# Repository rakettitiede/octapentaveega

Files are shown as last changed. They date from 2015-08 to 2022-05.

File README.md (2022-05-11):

# OctaPentaVeega

Fun hobby project to generate 32 x 16 characters of text on VGA output (or alternatively 64x64 pixel graphics, or split-screen graphics/text) from Attiny85 with 6x10 pixel font.

Data is read from UART at 9600bps. [Subset of ANSI escapes is supported](https://github.com/Jartza/octapentaveega/blob/master/vga_uart_protocol.txt).

Wiring 3 Attinys together gets you 8 color output :)

Links:
* <a href="https://www.youtube.com/watch?v=G1QWNDck0yU" target="_blank">Video: Ansi tester 8-color (ansitester.py)</a>
* <a href="https://www.youtube.com/watch?v=Vw5xGuLFy8Q" target="_blank">Video: Ansi tester Black & White (ansitester.py)</a>
* <a href="https://www.youtube.com/watch?v=YL0RwEtTN70" target="_blank">Video: Graphics mode (tricoder) & left scroll</a>
* <a href="https://www.youtube.com/watch?v=1iC2AHI5caI" target="_blank">Video: Full screen scroll (B/W)</a>
* <a href="https://www.youtube.com/watch?v=936m7FMS__c" target="_blank">Video: Full screen scroll (8-color)</a>
* <a href="https://drive.google.com/file/d/0B2dTzW9TMeBxN29YOVFsZFJ2Sm8/view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" target="_blank">Video: Multiple individual rows scroll (B/W)</a>
* <a href="https://drive.google.com/file/d/0B2dTzW9TMeBxQ1luNFhwcXl3QjA/view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" target="_blank">Picture: 6x10 pixel font</a>
* <a href="https://drive.google.com/file/d/0B2dTzW9TMeBxRzJOQVZMNFE0STg/view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" target="_blank">Picture: Generic (B/W)</a>

Board photos:
* <a href="https://drive.google.com/file/d/0B2dTzW9TMeBxaFFxam1uVW05NlE/view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" target="_blank">B/W board</a>
* <a href="https://drive.google.com/file/d/0B2dTzW9TMeBxRXVzSUNCT1h2NHM/view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" target="_blank">8-color board</a>
* <a href="https://drive.google.com/file/d/0B2dTzW9TMeBxX2VmQmw3aXhWUDA/view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" target="_blank">8-color board back</a>
* <a href="https://drive.google.com/file/d/0B2dTzW9TMeBxUDQ4QUduWDV2TFE/view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" target="_blank">Arduino shield, 8-color with level shifter (3.3 / 5v compatible)</a>

<p>
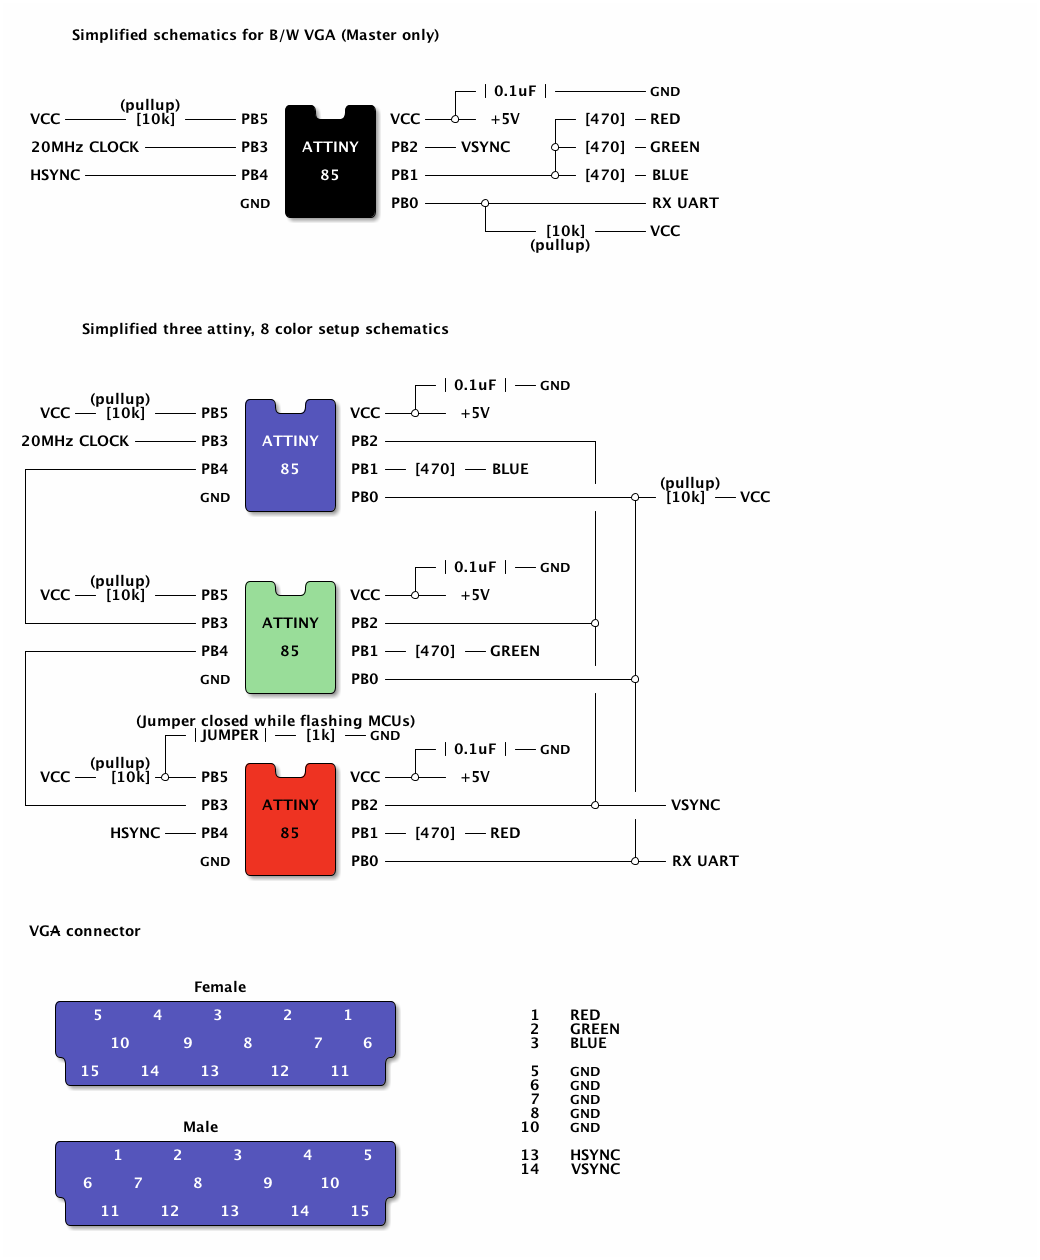
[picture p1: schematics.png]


//Jartza

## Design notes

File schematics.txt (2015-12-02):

Simplified schematics for B/W VGA (Master only):

                                           +--|0.1uF|----------GND
         (pullup)         /--\  /--\       |                                 
 VCC-------[10k]------PB5 |  \--/  | VCC---*-- +5V   +--[470]--RED
                          |cBLK    |                 |
 20MHz CLOCK----------PB3 | ATTINY | PB2----VSYNC    *--[470]--GREEN
                          |        |                 |
 HSYNC----------------PB4 |   85   | PB1-------------*--[470]--BLUE
                          |        |
                      GND |        | PB0------*----------------RX UART
                          \--------/          |
                                              +-----[10k]------VCC
                                                  (pullup)

Simplified three attiny, 8 color setup schematics:

                                       +--|0.1uF|---GND       
      (pullup)        /--\  /--\       |                      
  VCC---[10k]-----PB5 |  \--/  | VCC---*--- +5V                
                      |cBLU    |             
20MHz CLOCK-------PB3 | ATTINY | PB2---------------------+ 
                      |        |                         |     
+-----------------PB4 |   85   | PB1---[470]---BLUE      |   
|                     |        |                         |     (pullup)
|                 GND |        | PB0-------------------------*--[10k]---VCC
|                     \--------/                         |   |
|                                                        |   |
|                                                        |   |
|                                                        |   |
|                                      +--|0.1uF|---GND  |   |
|     (pullup)        /--\  /--\       |                 |   |
| VCC---[10k]-----PB5 |  \--/  | VCC---*--- +5V          |   |
|                     |cGRE    |                         |   |
+-----------------PB3 | ATTINY | PB2---------------------*   |
                      |        |                         |   |
+-----------------PB4 |   85   | PB1---[470]---GREEN     |   |
|                     |        |                         |   |
|                 GND |        | PB0-------------------------*
|                     \--------/                         |   |
|                                                        |   |
|       (Jumper closed while flashing MCUs)              |   |
|             +--|JUMPER|---[1k]---GND                   |   |
|             |                        +--|0.1uF|---GND  |   |
|    (pullup) |       /--\  /--\       |                 |   |
| VCC---[10k]-*---PB5 |  \--/  | VCC---*--- +5V          |   |
|                     |cRED    |                         |   |
+---------------- PB3 | ATTINY | PB2---------------------*-------VSYNC
                      |        |                             |
         HSYNC----PB4 |   85   | PB1---[470]---RED           |
                      |        |                             |
                  GND |        | PB0-------------------------*---RX UART
                      \--------/ 

VGA-connector:

                 Female                                                                     
   /---------------------------------\                                                    
   |   5     4     3      2     1    |             1 = RED
   |cBLU                             |             2 = GREEN
   |     10     9     8      7    6  |             3 = BLUE                                    
   \\                               //                                            
    | 15    14    13     12    11   |              5 = GND                           
    \-------------------------------/              6 = GND                                          
                                                   7 = GND                       
                                                   8 = GND                          
                Male                              10 = GND
   /---------------------------------\                                                    
   |     1     2     3      4     5  |            13 = HSYNC
   |cBLU                             |            14 = VSYNC
   |  6    7     8      9     10     |                                                         
   \\                               //                                            
    |   11    12    13     14    15 |                                              
    \-------------------------------/

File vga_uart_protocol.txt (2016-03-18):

Attiny85 VGA UART transfer:
===========================

Ascii-codes 32 .. 159 (decimal) are printed on screen as-is.

CR and LF are both treated as same; cursor is placed into
the beginning of next line. If cursor is already on last line, 
screen is scrolled up.

Limited subset of ANSI escapes is supported, and also few non-standard
escape codes.

ANSI sequence begins when "Escape" 0x1B (ascii 27 / ESC) character
followed by [ character is encountered.

List of supported ANSI escapes:
-----------------------------------------------------------------------------
Move cursor location		<ESC>[#row#;#column#H	#row# = 0 .. 13
				<ESC>[#row#;#column#f	#colunn# = 0 .. 31

Leaving both values undefined moves to (0,0):
<ESC>[H is equal to <ESC>[0;0H

Moving cursor outside the specified area has undefined effect.
-----------------------------------------------------------------------------
Clear screen and move cursor	<ESC>[2J
to upper left corner (0,0)
-----------------------------------------------------------------------------
Set colors (or reset to		<ESC>[#color#;#color#m
default color). Selected
color will stay active until
reset or new color selected.

#color# = color number		Foreground	Background
	black			   30		   40
	red			   31		   41
	green			   32		   42
	yellow			   33		   43
	blue			   34		   44
	magenta			   35		   45
	cyan			   36		   46
	white			   37		   47
	reset to defaults	   0

Color command supports maximum two arguments. Suggested way is to use
value 0 only alone in a command: <ESC>[0m resets colors to default.

Example: <ESC>[34;47m activates blue text with white background color.

Using other than supported color numbers has undefined effect.
-----------------------------------------------------------------------------
Disable wrap at the end		<ESC>[?7l	(lowercase L)
of line (cursor stays
in the last column).
-----------------------------------------------------------------------------
Enable wrap at the end		<ESC>[?7h
of line (cursor advances
to next line). Default
mode.
-----------------------------------------------------------------------------

Non-standard Escape codes
-----------------------------------------------------------------------------
Reset device			<ESC>c		Resets all variables and
						reboots device. Wait 1 second
						after this command before 
						sending new data.
-----------------------------------------------------------------------------
Scroll full screen left		<ESC>D		(Notice missing [ -char)
one column, emptying last
character of every row

Scroll commands are buffered if sent before the actual scroll has commenced.
-----------------------------------------------------------------------------
Scroll row left one 		<ESC>[#row#[	#row# = 0 .. 15
column, emptying last
character on row.

Example: <ESC>[9[ scrolls row 9 (10th row) left one column.
-----------------------------------------------------------------------------
Move cursor down		<ESC>[B		Moves cursor down.
-----------------------------------------------------------------------------
Move cursor forward		<ESC>[C		Moves cursor forward.
-----------------------------------------------------------------------------
Graphics/Text-mode split	<ESC>[#row#]	#row# = 0 .. 16
						Text-mode starts from #row#
						0 = full text
						16 = full graphics
						1..15 = split screen to
						        graphics / text
-----------------------------------------------------------------------------
Tricoder mode start		<ESC>G		In tricoder mode, each byte
						is sent 3 times: 
						Red, Green and Blue value
						separately. Useful in
						graphics mode as it allows
						you to draw any pixel
						with any of the 8 colors.
-----------------------------------------------------------------------------
Tricoder mode end		<ESC>T
-----------------------------------------------------------------------------
<ESC> followed by any other character than command prints the character to 
screen buffer as-is. 

Following ascii codes need to be escaped, if you want to print them to screen:
8, 10, 13, 27, 127

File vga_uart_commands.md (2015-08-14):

Attiny85 VGA ANSI escape codes:
===============================

Attiny85 VGA supports a limited subset of ANSI escapes.

ANSI sequence begins when "Escape" 0x1B (ascii 27 / ESC) character
followed by [ character is encountered.

Following ANSI escapes are supported:
-----------------------------------------------------------------------------
Move cursor location		<ESC>[#row#;#column#H	#row# = 0 .. 13
				<ESC>[#row#;#column#f	#colunn# = 0 .. 31

Leaving both values undefined moves to (0,0):
<ESC>[H is equal to <ESC>[0;0H

Moving cursor outside defined area has undefined effect.
-----------------------------------------------------------------------------
Clear screen and move cursor	<ESC>[2J
to upper left corner (0,0)
-----------------------------------------------------------------------------
Set colors (or reset to		<ESC>[#color#;#color#m
default color). Selected
color will stay active until
reset or new color selected.

#color# = color number		Foreground	Background
	black			   30		   40
	red			   31		   41
	green			   32		   42
	yellow			   33		   43
	blue			   34		   44
	magenta			   35		   45
	cyan			   36		   46
	white			   37		   47
	reset to defaults	   0

Color command supports maximum two arguments. Suggested way is to use
value 0 only alone in a command: <ESC>[0m resets colors to default.

Example: <ESC>[34;47m activates blue text with white background color.
-----------------------------------------------------------------------------

<ESC><ESC> sends ASCII character 27 to screen.

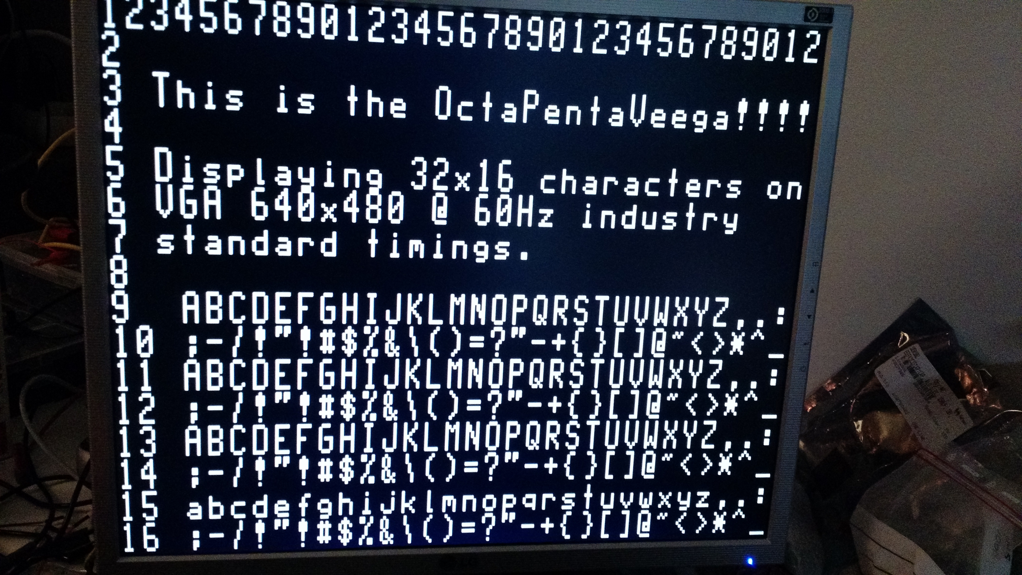
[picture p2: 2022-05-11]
pic/generic.jpg

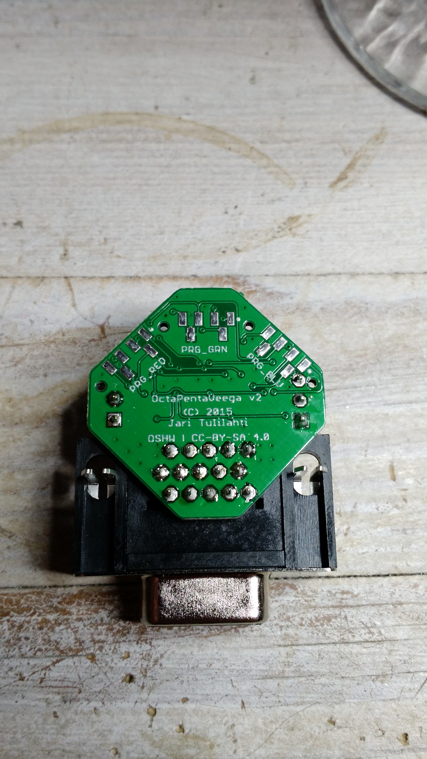
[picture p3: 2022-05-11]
pic/8colorboardback.jpg

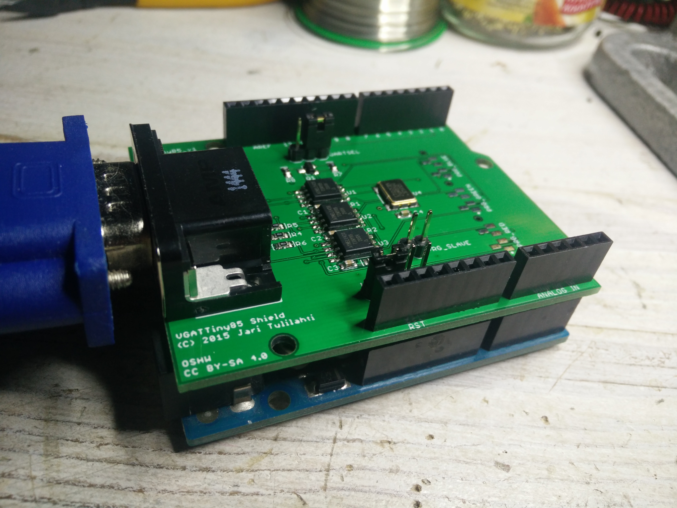
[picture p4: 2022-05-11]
pic/arduinoshield.jpg

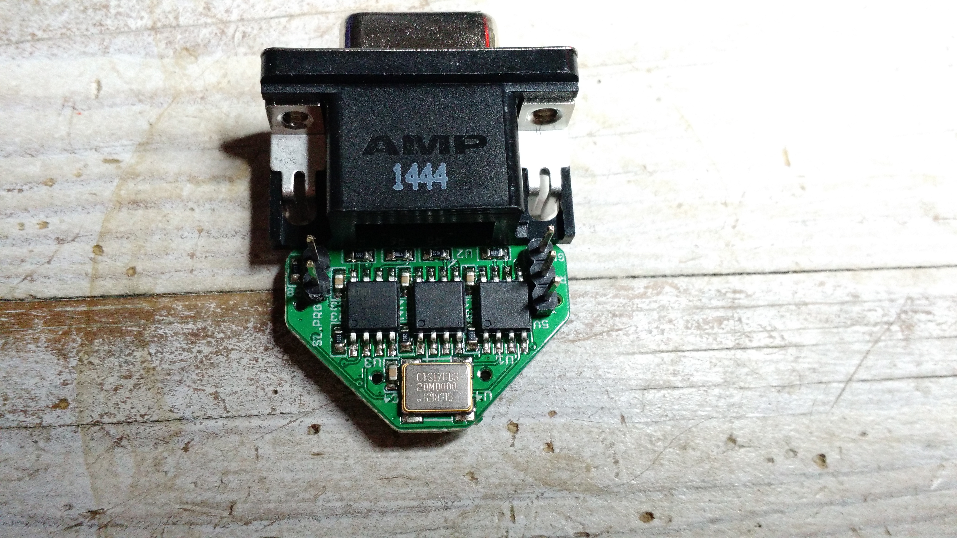
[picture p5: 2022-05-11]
pic/8colorboard.jpg

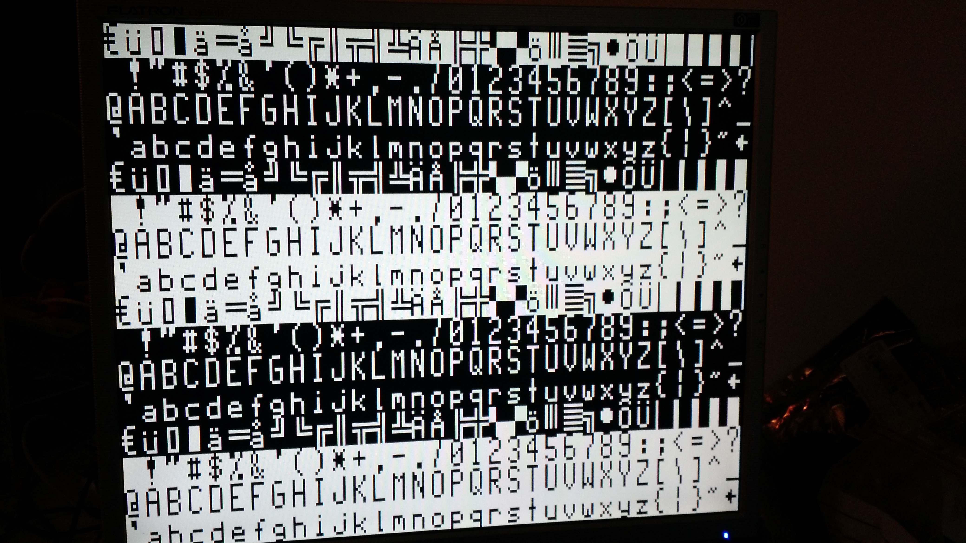
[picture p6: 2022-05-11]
pic/font.jpg

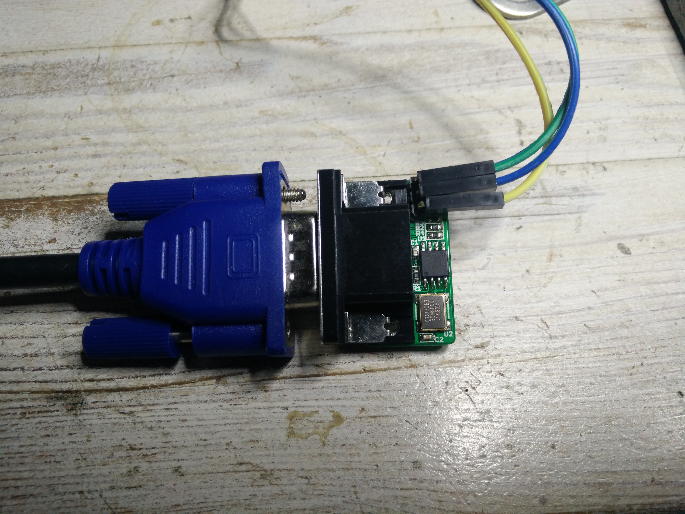
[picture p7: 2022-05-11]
pic/bwboard.jpg

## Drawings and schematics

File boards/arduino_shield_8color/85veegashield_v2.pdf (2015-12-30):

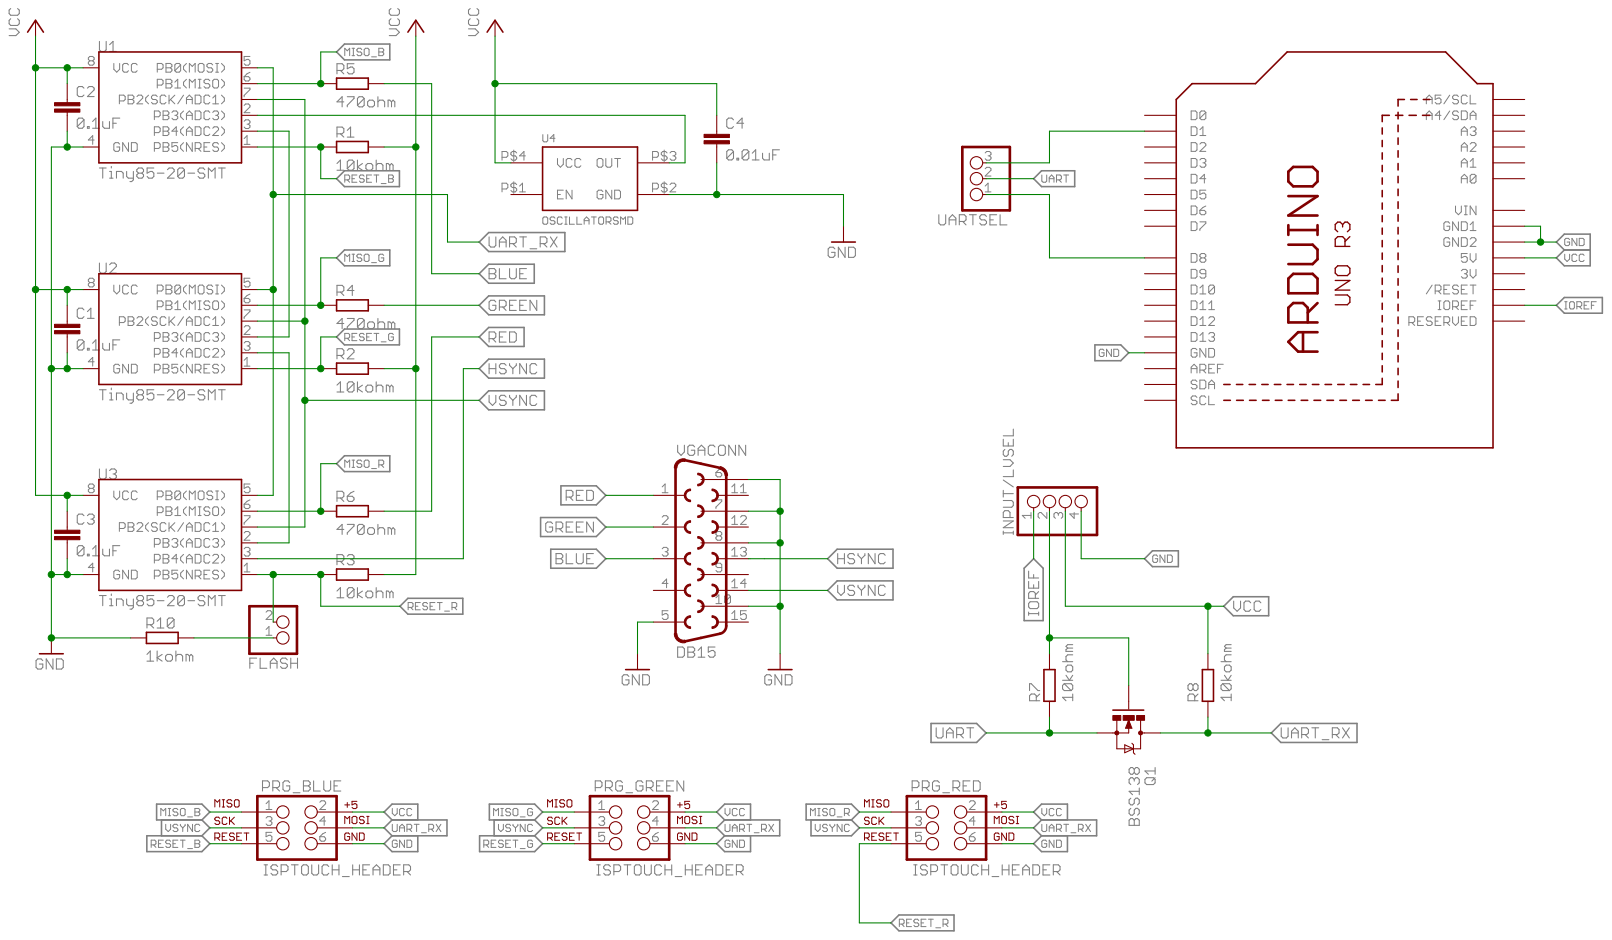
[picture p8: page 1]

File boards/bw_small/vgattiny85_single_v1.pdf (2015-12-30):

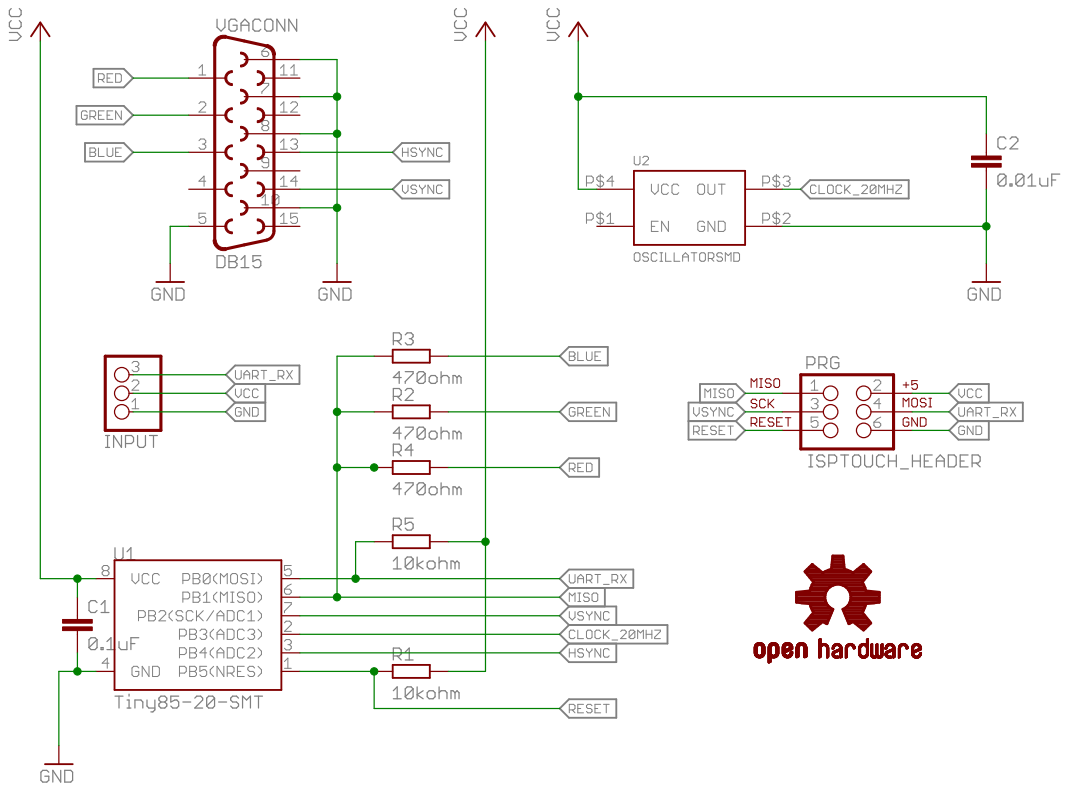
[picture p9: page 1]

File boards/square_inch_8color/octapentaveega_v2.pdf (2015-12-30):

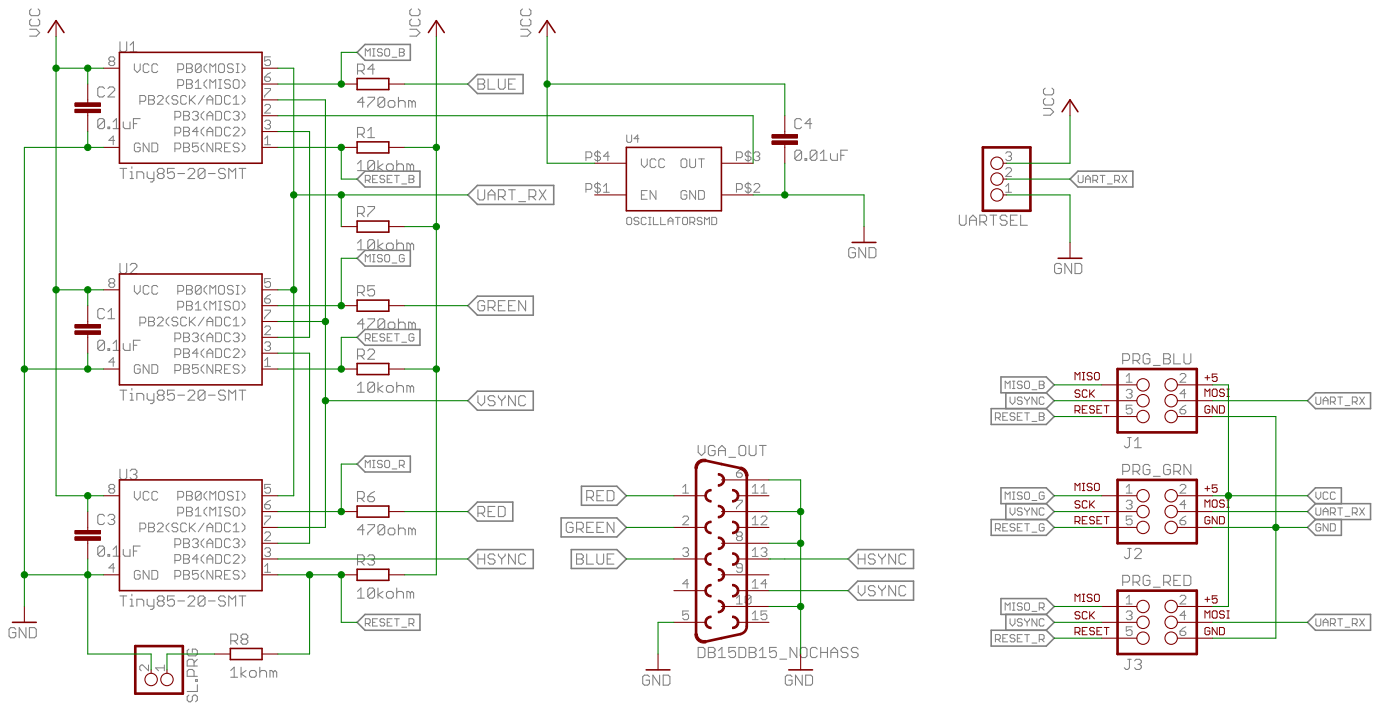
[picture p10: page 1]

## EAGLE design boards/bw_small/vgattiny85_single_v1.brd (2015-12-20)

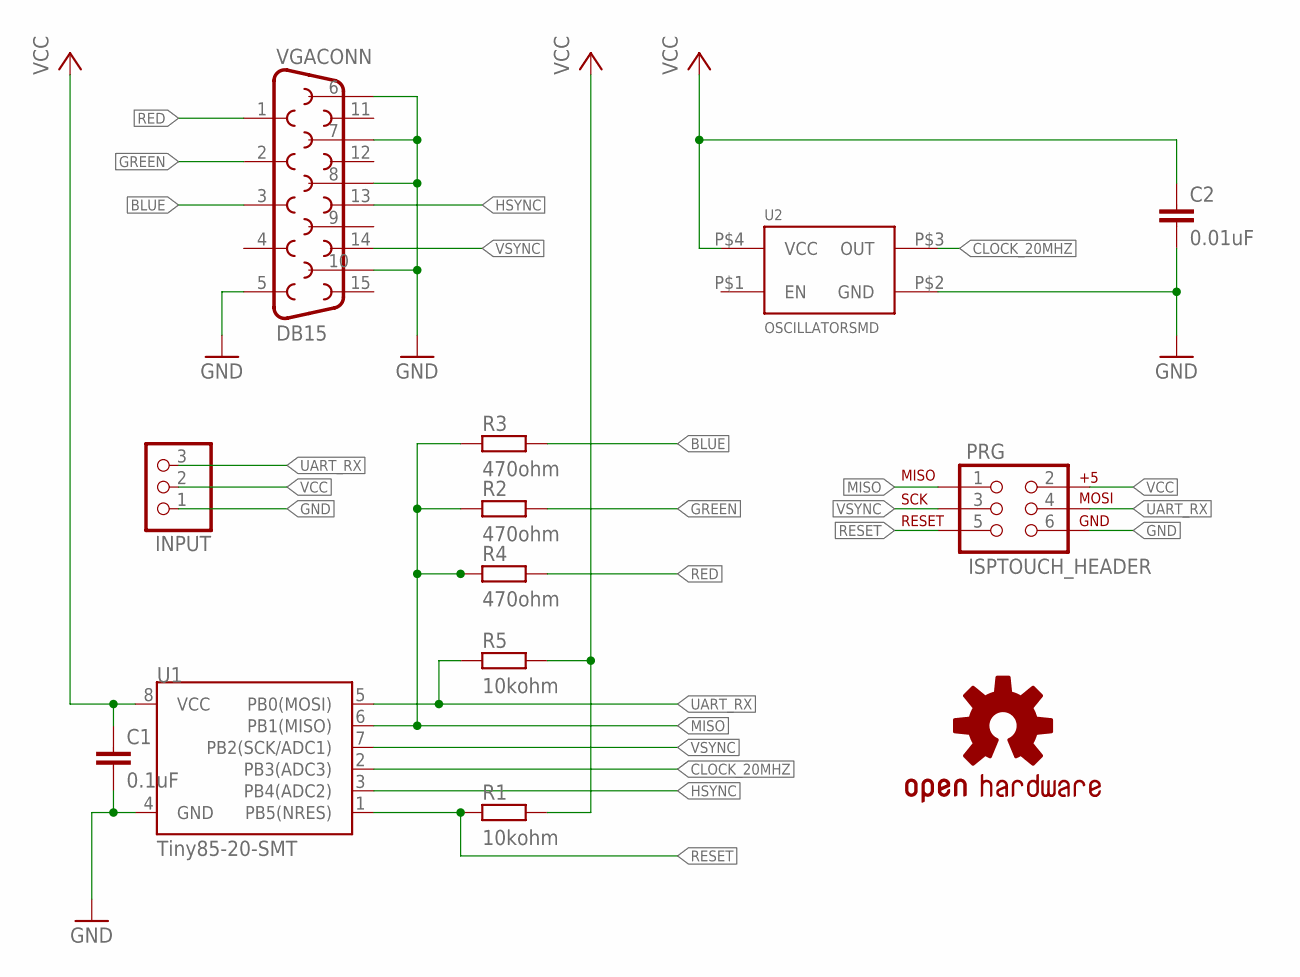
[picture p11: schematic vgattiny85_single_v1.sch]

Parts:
C1: 0.1uF; 0603-CAP
C2: 0.01uF; 0603-CAP
INPUT: PINHD-1X03_2.54-S; 1X03-S
LOGO1: OSHW-LOGOS; OSHW-LOGO-S
PRG: ISPTOUCH_HEADER; AVX_9188_6-WAY_MATING_GUIDE
R1, R5: 10kohm; R0603
R2, R3, R4: 470ohm; R0603
U1: Tiny85-20-SMT; SO08-EIAJ
U2: OSCILLATORSMD; CRYSTAL-SMD-7X5
VGACONN: DB15

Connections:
BLUE: R3.2, VGACONN.3
CLOCK_20MHZ: U1.2 (PB3(ADC3)), U2.P$3 (OUT)
GND: C1.2, C2.2, INPUT.1, PRG.6, U1.4 (GND), U2.P$2 (GND), VGACONN.5, VGACONN.6, VGACONN.7, VGACONN.8, VGACONN.10
GREEN: R2.2, VGACONN.2
HSYNC: U1.3 (PB4(ADC2)), VGACONN.13
MISO: PRG.1, R2.1, R3.1, R4.1, U1.6 (PB1(MISO))
RED: R4.2, VGACONN.1
RESET: PRG.5, R1.1, U1.1 (PB5(NRES))
UART_RX: INPUT.3, PRG.4, R5.1, U1.5 (PB0(MOSI))
VCC: C1.1, C2.1, INPUT.2, PRG.2, R1.2, R5.2, U1.8 (VCC), U2.P$4 (VCC)
VSYNC: PRG.3, U1.7 (PB2(SCK/ADC1)), VGACONN.14

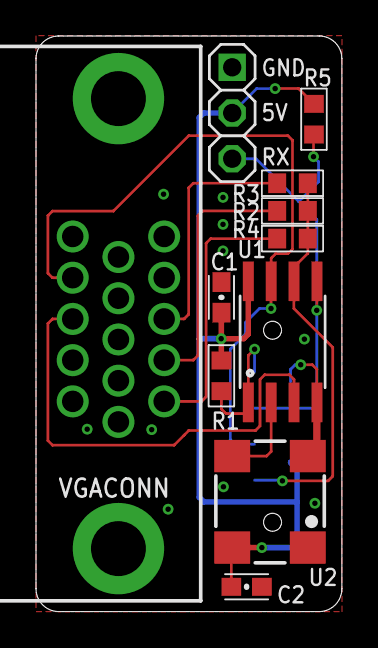
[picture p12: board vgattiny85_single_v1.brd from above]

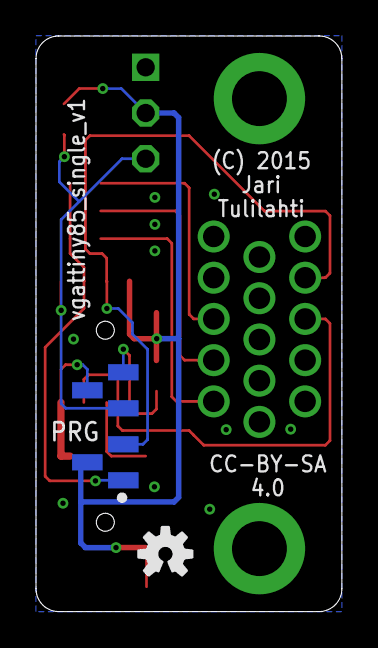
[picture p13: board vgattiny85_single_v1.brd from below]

Board: 2 copper layers, 17.0 x 32.0 mm, 13 parts (2 on the bottom side), 11 nets.

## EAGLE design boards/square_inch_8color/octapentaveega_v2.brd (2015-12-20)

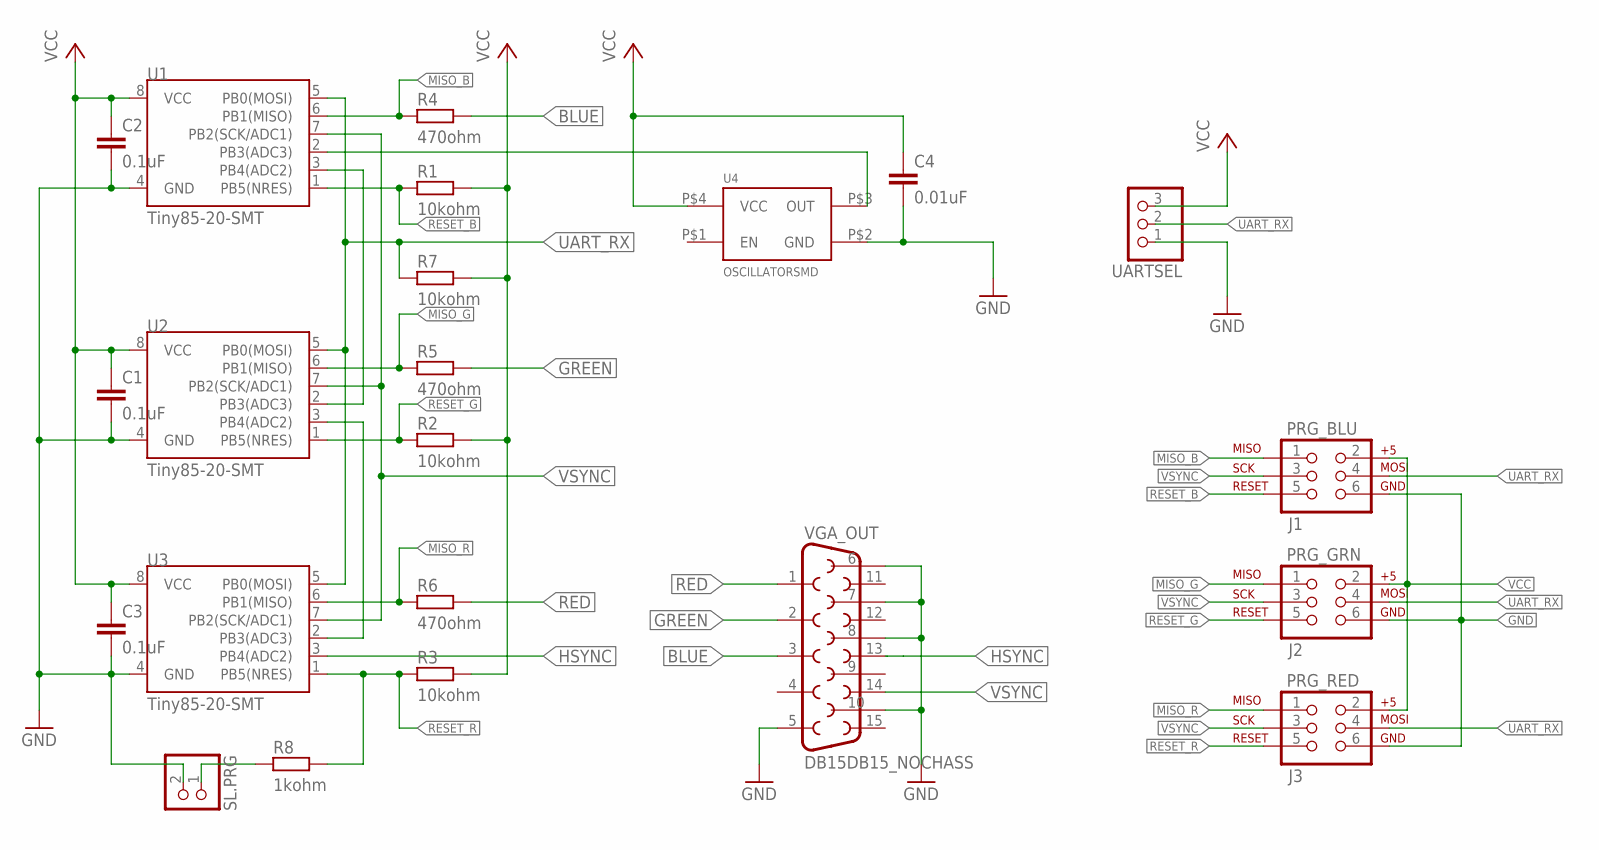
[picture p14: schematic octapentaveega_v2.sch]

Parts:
C1, C2, C3: 0.1uF; C0603
C4: 0.01uF; C0603
PRG_BLU: J1; AVX_9188_6-WAY_MATING_GUIDE
PRG_GRN: J2; AVX_9188_6-WAY_MATING_GUIDE
PRG_RED: J3; AVX_9188_6-WAY_MATING_GUIDE
R1, R2, R3, R7: 10kohm; R0603
R4, R5, R6: 470ohm; R0603
R8: 1kohm; R0603
SL.PRG: PINHD-1X02_2.54-S; 1X02-S
U1, U2, U3: Tiny85-20-SMT; SO08-EIAJ
U4: OSCILLATORSMD; CRYSTAL-SMD-7X5
UARTSEL: PINHD-1X03_2.54-S; 1X03-S
VGA_OUT: DB15DB15_NOCHASS; DB15_NOCHASS

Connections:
BLUE: R4.2, VGA_OUT.3
GND: C1.2, C2.2, C3.2, C4.2, PRG_BLU.6, PRG_GRN.6, PRG_RED.6, SL.PRG.2, U1.4 (GND), U2.4 (GND), U3.4 (GND), U4.P$2 (GND), UARTSEL.1, VGA_OUT.5, VGA_OUT.6, VGA_OUT.7, VGA_OUT.8, VGA_OUT.10
GREEN: R5.2, VGA_OUT.2
HSYNC: U3.3 (PB4(ADC2)), VGA_OUT.13
MISO_B: PRG_BLU.1, R4.1, U1.6 (PB1(MISO))
MISO_G: PRG_GRN.1, R5.1, U2.6 (PB1(MISO))
MISO_R: PRG_RED.1, R6.1, U3.6 (PB1(MISO))
unnamed: U1.2 (PB3(ADC3)), U4.P$3 (OUT)
unnamed: U1.3 (PB4(ADC2)), U2.2 (PB3(ADC3))
unnamed: U2.3 (PB4(ADC2)), U3.2 (PB3(ADC3))
unnamed: R8.1, SL.PRG.1
RED: R6.2, VGA_OUT.1
RESET_B: PRG_BLU.5, R1.1, U1.1 (PB5(NRES))
RESET_G: PRG_GRN.5, R2.1, U2.1 (PB5(NRES))
RESET_R: PRG_RED.5, R3.1, R8.2, U3.1 (PB5(NRES))
UART_RX: PRG_BLU.4, PRG_GRN.4, PRG_RED.4, R7.1, U1.5 (PB0(MOSI)), U2.5 (PB0(MOSI)), U3.5 (PB0(MOSI)), UARTSEL.2
VCC: C1.1, C2.1, C3.1, C4.1, PRG_BLU.2, PRG_GRN.2, PRG_RED.2, R1.2, R2.2, R3.2, R7.2, U1.8 (VCC), U2.8 (VCC), U3.8 (VCC), U4.P$4 (VCC), UARTSEL.3
VSYNC: PRG_BLU.3, PRG_GRN.3, PRG_RED.3, U1.7 (PB2(SCK/ADC1)), U2.7 (PB2(SCK/ADC1)), U3.7 (PB2(SCK/ADC1)), VGA_OUT.14

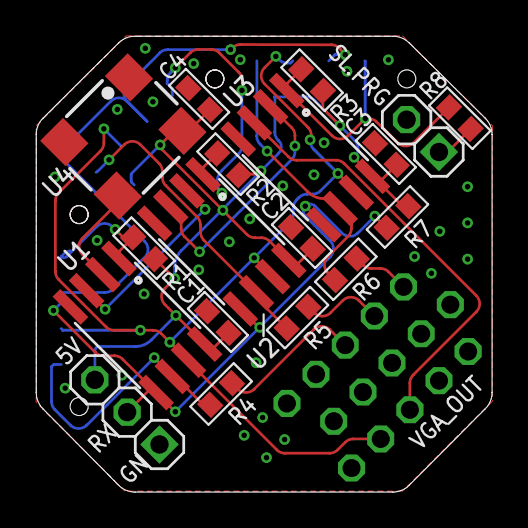
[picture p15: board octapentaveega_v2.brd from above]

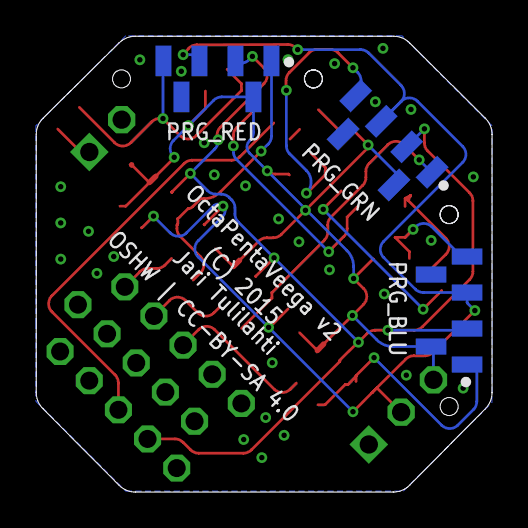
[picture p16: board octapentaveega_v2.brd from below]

Board: 2 copper layers, 25.3 x 25.3 mm, 22 parts (3 on the bottom side), 18 nets.

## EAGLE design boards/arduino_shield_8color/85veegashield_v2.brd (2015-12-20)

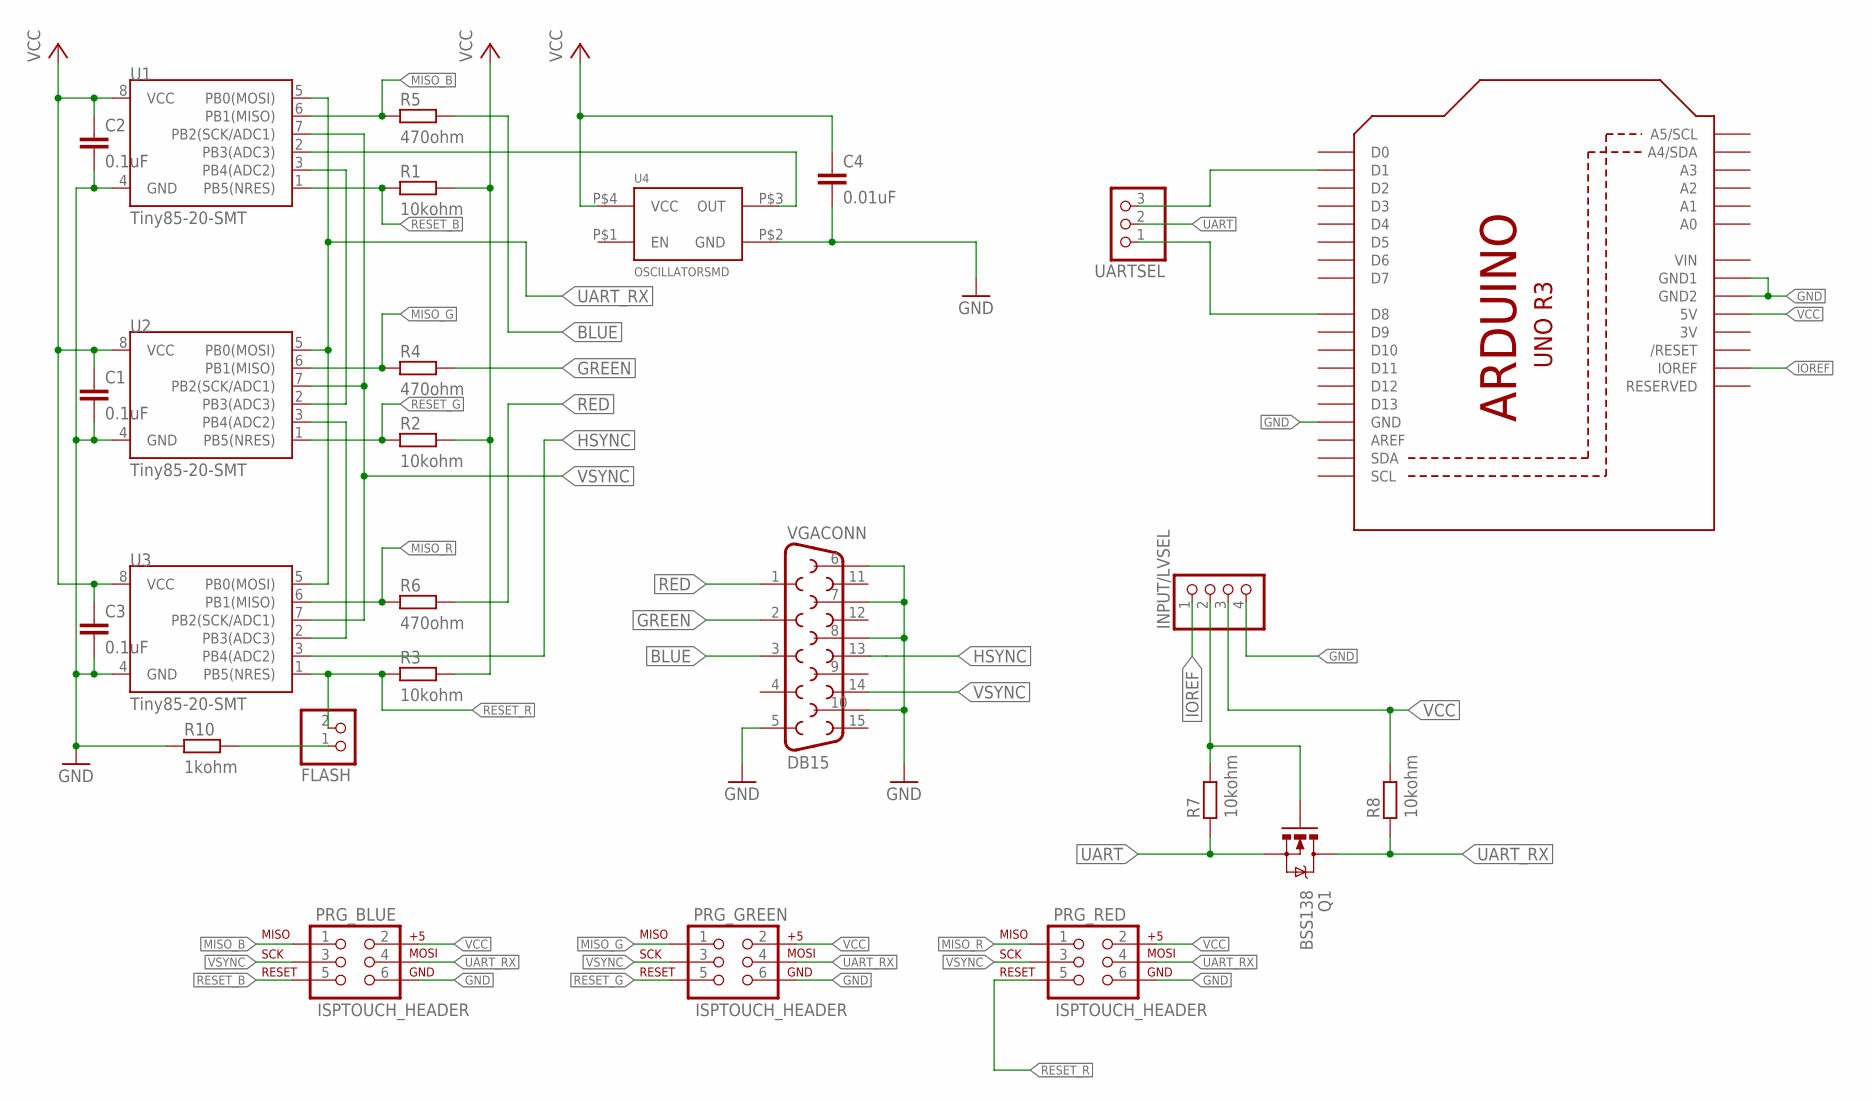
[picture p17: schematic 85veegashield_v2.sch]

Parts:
C1, C2, C3: 0.1uF; 0603-CAP
C4: 0.01uF; 0603-CAP
FLASH: PINHD-1X02_2.54-S; 1X02-S
INPUT/LVSEL: PINHD-1X04_2.54-S; 1X04-S
PRG_BLUE: ISPTOUCH_HEADER; AVX_9188_6-WAY_MATING_GUIDE
PRG_GREEN: ISPTOUCH_HEADER; AVX_9188_6-WAY_MATING_GUIDE
PRG_RED: ISPTOUCH_HEADER; AVX_9188_6-WAY_MATING_GUIDE
Q1: BSS138; SOT23
R1, R2, R3, R7, R8: 10kohm; R0603
R4, R5, R6: 470ohm; R0603
R10: 1kohm; R0603
U1, U2, U3: Tiny85-20-SMT; SO08-EIAJ
U4: OSCILLATORSMD; CRYSTAL-SMD-7X5
U$1: ARDUINOR3-DIMENSION; ARDUINOR3
UARTSEL: PINHD-1X03_2.54-S; 1X03-S
VGACONN: DB15

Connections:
3V: U$1.3V
BLUE: R5.2, VGACONN.3
FOO: INPUT/LVSEL.2, Q1.1 (G), R7.2
GND: C1.2, C2.2, C3.2, C4.2, INPUT/LVSEL.4, PRG_BLUE.6, PRG_GREEN.6, PRG_RED.6, R10.1, U1.4 (GND), U2.4 (GND), U3.4 (GND), U4.P$2 (GND), U$1.GND, U$1.GND1, U$1.GND2, VGACONN.5, VGACONN.6, VGACONN.7, VGACONN.8, VGACONN.10
GREEN: R4.2, VGACONN.2
HSYNC: U3.3 (PB4(ADC2)), VGACONN.13
IOREF: INPUT/LVSEL.1, U$1.IOREF
MISO_B: PRG_BLUE.1, R5.1, U1.6 (PB1(MISO))
MISO_G: PRG_GREEN.1, R4.1, U2.6 (PB1(MISO))
MISO_R: PRG_RED.1, R6.1, U3.6 (PB1(MISO))
unnamed: U1.2 (PB3(ADC3)), U4.P$3 (OUT)
unnamed: U1.3 (PB4(ADC2)), U2.2 (PB3(ADC3))
unnamed: U2.3 (PB4(ADC2)), U3.2 (PB3(ADC3))
unnamed: U$1.D1, UARTSEL.3
unnamed: FLASH.1, R10.2
unnamed: U$1.D8, UARTSEL.1
RED: R6.2, VGACONN.1
RESET_B: PRG_BLUE.5, R1.1, U1.1 (PB5(NRES))
RESET_G: PRG_GREEN.5, R2.1, U2.1 (PB5(NRES))
RESET_R: FLASH.2, PRG_RED.5, R3.1, U3.1 (PB5(NRES))
UART: Q1.2 (S), R7.1, UARTSEL.2
UART_RX: PRG_BLUE.4, PRG_GREEN.4, PRG_RED.4, Q1.3 (D), R8.1, U1.5 (PB0(MOSI)), U2.5 (PB0(MOSI)), U3.5 (PB0(MOSI))
VCC: C1.1, C2.1, C3.1, C4.1, INPUT/LVSEL.3, PRG_BLUE.2, PRG_GREEN.2, PRG_RED.2, R1.2, R2.2, R3.2, R8.2, U1.8 (VCC), U2.8 (VCC), U3.8 (VCC), U4.P$4 (VCC), U$1.5V
VIN: U$1.VIN
VSYNC: PRG_BLUE.3, PRG_GREEN.3, PRG_RED.3, U1.7 (PB2(SCK/ADC1)), U2.7 (PB2(SCK/ADC1)), U3.7 (PB2(SCK/ADC1)), VGACONN.14

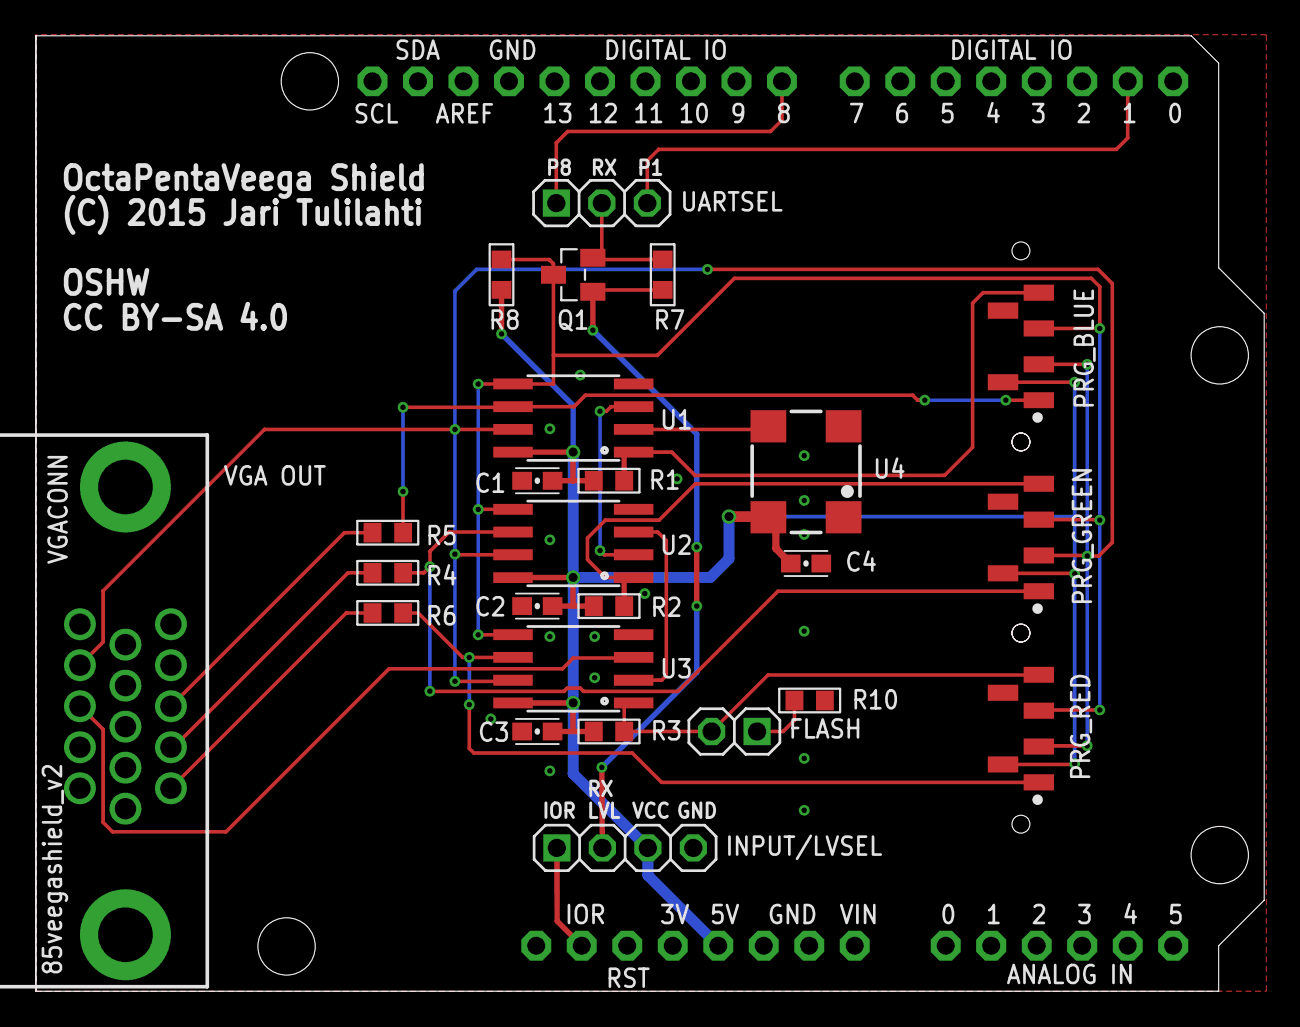
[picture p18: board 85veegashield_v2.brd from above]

Board: 2 copper layers, 68.6 x 53.3 mm, 26 parts (0 on the bottom side), 23 nets.

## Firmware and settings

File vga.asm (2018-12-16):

;;;;;;;;;;;;;;;;;;;;;;;;;;;;;;;;;;;;;;;;;;;;;;;;;;;;;;;;;;;;;;;;;;;;;;;;;;;;;;;;
;;                                                                            ;;
;;  32 x 16 character VGA output with UART for Attiny85.                      ;;
;;                                                                            ;;
;;  (C) Copyright 2015-2016 Jari Tulilahti                                    ;;
;;                                                                            ;;
;;  All right and deserved.                                                   ;;
;;                                                                            ;;
;;  Licensed under the Apache License, Version 2.0 (the "License");           ;;
;;  you may not use this file except in compliance with the License.          ;;
;;  You may obtain a copy of the License at                                   ;;
;;                                                                            ;;
;;      http://www.apache.org/licenses/LICENSE-2.0                            ;;
;;                                                                            ;;
;;  Unless required by applicable law or agreed to in writing, software       ;;
;;  distributed under the License is distributed on an "AS IS" BASIS,         ;;
;;  WITHOUT WARRANTIES OR CONDITIONS OF ANY KIND, either express or implied.  ;;
;;  See the License for the specific language governing permissions and       ;;
;;  limitations under the License.                                            ;;
;;                                                                            ;;
;;;;;;;;;;;;;;;;;;;;;;;;;;;;;;;;;;;;;;;;;;;;;;;;;;;;;;;;;;;;;;;;;;;;;;;;;;;;;;;;

.include "tn85def.inc"

; Registers have been named for easier access.
; in addition we use all of the X, Y and Z
; register pairs for pointers to different buffers
;
; X (r26:r27) is pointer to screen buffer, also used while
;             clearing the screen
; Y (r28:r29) is pointer to either predraw, or currently being
;             drawn buffer
; Z (r30:r31) pointer is used for fetching the data from flash
;             with lpm instruction
;

.def zero               = r0            ; Register for value 0
.def one                = r1            ; Register for value 1
.def seq_cnt            = r2            ; Counter for several sequences
.def row_cnt            = r3            ; Vertical pixel counter
.def char_row           = r4            ; Predraw-buffer x-offset
.def uart_seq           = r5            ; UART sequence
.def uart_next          = r6            ; Next UART sequence
.def clear_cnt          = r7            ; Screen clear counter
.def uart_byte          = r8            ; UART receiving counter & data
.def color_fg           = r9            ; Foreground color
.def color_bg           = r10           ; Background (4..7) color
.def ansi_val1          = r11           ; Storage for ANSI cmd value
.def ansi_val2          = r12           ; Storage for ANSI cmd value
.def vline_lo           = r13           ; Vertical line low byte
.def vline_hi           = r14           ; Vertical line high byte
.def scroll_row         = r15           ; Row number for horizontal scroll
.def temp               = r16           ; Temporary register
.def temp2              = r17           ; Temporary register 2
.def font_hi            = r18           ; Font Flash addr high byte
.def scroll_lo          = r19           ; Screen scroll offset low
.def scroll_hi          = r20           ; Screen scroll offset high
.def ansi_state         = r21           ; ANSI command states described below
.def uart_buf           = r22           ; UART buffer
.def state              = r23           ; Bitmask for states described below
.def cursor_lo          = r24           ; Cursor offset low
.def cursor_hi          = r25           ; Cursor offset high
                                        ; r26 .. r31 described above

; state: (bits)
;
.equ st_clear           = 0             ; Screen clear mode active bit
.equ st_wrap            = 1             ; Wrap mode active bit
.equ st_uart            = 2             ; UART data in buffer
.equ st_scroll          = 3             ; Scroll-clear in action
.equ st_left            = 4             ; Scroll row left
.equ st_full_left       = 5             ; Scroll full screen
.equ st_tricoder        = 6             ; "Tricoder"-mode
.equ st_clear_val       = (1 << 0)      ; Value to set/clear clear mode
.equ st_wrap_val        = (1 << 1)      ; Value to set/clear wrap mode
.equ st_uart_val        = (1 << 2)      ; Value to set/clear UART buffer state
.equ st_scroll_val      = (1 << 3)      ; Value to set/clear scroll-clear state
.equ st_left_val        = (1 << 4)      ; Value to set/clear row-scroll
.equ st_full_left_val   = (1 << 5)      ; Value to set/clear full-screen-scroll
.equ st_tricoder_val    = (1 << 6)      ; Value to set/clear tricoder

; ansi_state: (value)
;
; 0 : None
; 1 : ESC received
; 2 : Opening bracket "[" received
; 3 : Two values received


; Constants
;
.equ UART_WAIT          = 138           ; HSYNC timer value where we start to
                                        ; look for UART samples (or handle
                                        ; data received)
.equ HSYNC_WAIT         = 2             ; HSYNC value to start precalculating
                                        ; the pixels and drawing to screen
.equ JITTERVAL          = 248           ; Must be in sync with HSYNC_WAIT value.
                                        ; We want Timer0 counter to be 0-4 in
                                        ; jitterfix label. AVR Studio simulator
                                        ; was used to sync this value.
.equ VSYNC_LOW          = 490 - 256     ; Turn VSYNC low on this vertical line
.equ VSYNC_HIGH         = VSYNC_LOW + 2 ; Turn VSYNC high on this vertical line
.equ VISIBLE            = 480 - 256     ; Visible vline count
.equ UART_XOR           = 124           ; UART sequence magic XORing value
.equ UART_INIT          = 100           ; UART sequence initial value after start
.equ UART_FIRST         = 24            ; UART first sequence
.equ ALT_XOR            = 32            ; Buffer flipping value
.equ DEFAULT_COLOR_FG   = 7             ; White foreground
.equ DEFAULT_COLOR_BG   = 0             ; Black background

; Pins used for different signals
;
.equ UART_PIN           = PB0
.equ RGB_PIN            = PB1
.equ VSYNC_PIN          = PB2
.equ HSYNC_PIN          = PB4

; General purpose IO registers used as storage
;
.equ LEFT_CNT           = GPIOR0
.equ SPLIT_ROW          = GPIOR1
.equ TRICODE_CNT        = GPIOR2


; All of the 512 byte SRAM is used for screen buffer.
;
.dseg
.org 0x60

screenbuf:
        .byte 512
screen_end:

; Start the code section. 
; Only two vectors used. RESET for all versions
; and INT0 for slaves (synchronization)
.cseg
.org 0x00

vectors:
        rjmp main
.ifdef VGA_SLAVE
        rjmp slave_sync
.endif
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

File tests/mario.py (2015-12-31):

import serial
import time
import random
import sys

# Give port name of your UART as first argument. No error checking
# here, sorry.
#
ser = serial.Serial(sys.argv[1], 9600,  timeout = 1)

serwrite = lambda x: ser.write(bytearray(map(ord, x)))
move_to = lambda x, y: serwrite("\x1B[{0};{1}H".format(y, x))

#serwrite("xxxxx\x08") # dismiss if we're left in ANSI mode...
serwrite("\x1B[16]") # Graphics mode
serwrite("\x1B[m") # Reset colors
serwrite("\x1B[?7l") # disable wrap
serwrite("\x1BG") # Tricoder mode

mario=[
#red
[
"                                                                                                                                                                                                                                                                                                                                                                                                                                                                                                                                                                                                                                                                                                                                                                                                                                                                                                                                                                                                       ",
"                                                                                                                                                                                                                                                                                                                                                                                                                                                                                                                                                                                                                                                                                                                                                                                                                                                                                                                                                                                                       ",
"                                                                                                                                                                                                                                                                                                                                                                                                                                                                                                                                                                                                                                                                                                                                                                                                                                                                                                                                                                                                       ",
"                                                                                                                                                                                                                                                                                                                                                                                                                                                                                                                                                                                                                                                                                                                                                                                                                                                                                                                                                                                                       ",
"                                                                                                                                                                                                                                                                                                                                                                                                                                                                                                                                                                                                                                                                                                                                                                                                                                                                                                                                                                                                       ",
"                                                                                                                                                                                                                                                                                                                                                                                                                                                                                                                                                                                                                                                                                                                                                                                                                                                                                                                                                                                                       ",
"                                                                                                                                                                                                                                                                                                                                                                                                                                                                                                                                                                                                                                                                                                                                                                                                                                                                                                                                                                                                       ",
"                                                                                            ...                                                                           ..   ..                                                                                                                                       ..                                                                            ..  ...                                                                                                                                      ...                                                                           ..   ..                                                                                                                                       ..                                                                            ..  ..                                                                                                                                    ",
"                                                                                            ....                                                                          ........                                                                                                                                     ....                                                                          .... ....                                                                                                                                     ....                                                                         .........                                                                                                                                     ....                                                                          .... ....                                                                                                                                  ",
"                                                                                          ......                                                                        ............                                                                                                                                  .......                                                                      ............                                                                                                                                  .......                                                                       ............                                                                                                                                  .......                                                                      ............                                                                                                                                 ",
"                                                                                         .........                                                                     ..............                                                                                                                                .........                                                                     .............                                                                                                                                .........                                                                     .............                                                                                                                                 .........                                                                    ..............                                                                                                                                ",
"                                           .                                             .........                                .   .    .                           .............                                                                                  .                                              ........                                .    .   .                            .............                                                                                  .                                             .........                                .   .    .                           .............                                                                                  .                                              ........                                .    .   .                            .............                                                                ....              .                                             ",
"                                          ...                                             ........                               ... .... ...                           .............                                                                                ....                                             ........                              .... ... ....                           ............                                                                                 ...                                             ........                               ... .... ...                           .............                                                                                ....                                             ........                              .... ... ....                           ............                                                                ......           ...                                            ",
"                                         .....                                              . ..                                ..............                            . . ....                                                                                   ....                                               . .                                ..............                            .... . .                                                                                   .....                                              . ..                                ..............                            . . ....                                                                                   ....                                              ....                                ..............                            .... . .                                                                    .....          .....                                           ",
"                                        .......                                                                               .................                                                                                                                    ........                                                                               .................                                                                                                                   ........                                                                               .................                                                                                                                    ........                                                                               .................                                                                                                       ....        ........                                          ",
"                                       .........                                                                              ..................                                                                                                                  .........                                                                              ..................                                                                                                                   .........                                                                              ..................                                                                                                                  .........                                                                              ..................                                                                                                        ...        .........                                         ",
"                                        ........                                                                              ..................                                                                                                                   ........                                                                               .................           ..                                                                                                       ........            ...                                                               ..................                                                                                                                   ........                                                                               .................                                                                                                         ..        .........                                         ",
"                                         .......                                                                                ................                                                                                                                    .......                                                                                ................          ....                                                                                                       ......            .....                                                                ...............                                                                                                                     .......                                                                                ................                                                                                                          .          ......                                          ",
"                                                                                                                                                                                                                                                                                                                                                                                    ......                                                                                                                        .....                                                                                                                                                                                                                                                                                                                                                                                                                    ..                                                          ",
"                                                                                                                                                                                                                                                                                                                                                                                    .....                                                                                                                         .....                                                                                                                                                                                                                                                                                                                                                                                                                    ..                                                          ",
"                                                                                                    .....                                                                                                                                                                                                                                                                    ..........  ..........................             ..................                                                                .....                                                  ..............                  ...................                                                                                                                                                                                                                                                               ..........                                      .                                                           ",
"                                                                                                    .....                                                                                                                                                                                                                                                                    .....................................              ..................                                                                .....                                                  ..............                  ..................                                                                                                                                                                                                                                                                .... ....                                       ..                                                          ",
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

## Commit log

2015-07-07 Start moving to assembler
2015-07-10 Add fuses for external clock
2015-07-24 PWM testing
2015-08-03 Avra has bugs :(
    [vga.asm]
2015-08-03 Testing UART
2015-08-03 Ahh. Small timing fix and everything works
    [vga.asm]
2015-08-05 Add spec-draft of UART commands to be implemented
2015-08-08 Much simpler, glitch-free screen clearing
    [vga.asm]
2015-08-08 Prevent double-clearing during screen-clear
    [vga.asm]
2015-08-08 Fix indent, remove clear_mode and insert general state bitfield-register instead
    [vga.asm]
2015-08-09 Simplify UART
2015-08-10 swap instead of lsl
    [vga.asm]
2015-08-13 Hawk-eye-Arttu spotted a bug
    [vga.asm]
2015-08-14 Fix color value setting
    [vga.asm]
2015-08-14 Small fixes to ANSI code parsing. Also added enable/disable wrap code
    [vga.asm]
2015-08-14 Add 'schematics'
2015-08-14 Update schematics
2015-08-14 Update schematics #2
2015-08-17 Reverse fuse and flashing order
2015-08-22 Fix bug in color handling
    [vga.asm]
2015-08-22 ASCII Schematics
2015-08-23 Fix bug in schematics
    [ansitester.py]
2015-08-23 Add cap to schematics
2015-08-23 Add VGA connector to schematics
2015-08-23 Update connector diagram
2015-08-23 Update connector diagram #2
2015-10-30 Rename UART doc
2015-10-30 ESC ESC
2015-10-30 Start fixing UART doc
2015-10-30 UART doc table
2015-10-30 Revert "UART doc table"
    This reverts commit 4f61a6cebca707a01b4579eb6891bbc2ecd14280.
2015-11-04 Slight fix for formatting
    [vga.asm]
2015-11-05 Oops, indent error in ansitester
    [ansitester.py]
2015-11-09 Fix wrap mode control characters
    [vga.asm]
2015-11-09 Final fix for wrap-mode escape code
    [ansitester.py, vga.asm]
2015-11-11 Add resistor to schematics for Flashing jumper
2015-11-11 Modify ansitester for shorter line length
    [ansitester.py]
2015-11-11 Update schematics into ditaa-compatible and generate png
2015-11-11 Make schematics render more nicely with ditaa
2015-11-11 Make schematics render more nicely with ditaa #2
2015-11-12 improve schematics with ditaa
2015-11-12 improve schematics with ditaa #2
2015-11-12 improve schematics with ditaa #3
2015-11-12 improve schematics with ditaa #4
2015-11-12 Add schematics to README
2015-11-12 Add UART as argument for ansitester
2015-11-12 Update schematics URL in README
2015-11-14 Fix Ansitester.py with flush
    [ansitester.py]
2015-11-16 Switch front and back porches in hsync
2015-11-17 Add voltage levels to RGB
2015-11-30 Slight fixes to left scroll
    [vga.asm]
2015-11-30 Couldn't fix the minor glitches in scroll... have to re-check later
    [vga.asm]
2015-12-01 No more UART chars missing while scrolling
    [vga.asm]
2015-12-01 Even better left scrolling without lost UART characters
2015-12-19 Preliminary support for left scroll - with small glitches
    [ansitester.py, bw_left_scroll.py, vga.asm]
2015-12-19 Small fix to ansitester.py
    [ansitester.py]
2015-12-20 Tiny bugfix of scroll
    [ansitester.py, vga.asm]
2015-12-20 Add PCBs. Eagle files + Gerbers
    [85veegashield_v2.brd, 85veegashield_v2.sch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]
2015-12-20 Slightly fixing various stuff
    [ansitester.py, vga.asm]
2015-12-30 Add schematics and hex files

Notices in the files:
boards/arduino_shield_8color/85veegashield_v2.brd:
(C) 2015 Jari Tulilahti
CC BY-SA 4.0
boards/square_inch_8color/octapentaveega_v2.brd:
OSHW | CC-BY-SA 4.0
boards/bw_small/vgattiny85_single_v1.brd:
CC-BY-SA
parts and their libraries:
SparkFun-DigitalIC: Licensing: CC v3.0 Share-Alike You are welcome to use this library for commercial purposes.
